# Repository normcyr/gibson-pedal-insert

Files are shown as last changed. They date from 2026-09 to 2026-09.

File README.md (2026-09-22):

# Gibson Bicycle Pedal Insert

3D-printable replacement insert for vintage Gibson bicycle pedals.

These black plastic inserts were originally used in Gibson bicycle
pedals. This project provides a modern replacement that can be
3D-printed for restoration purposes.

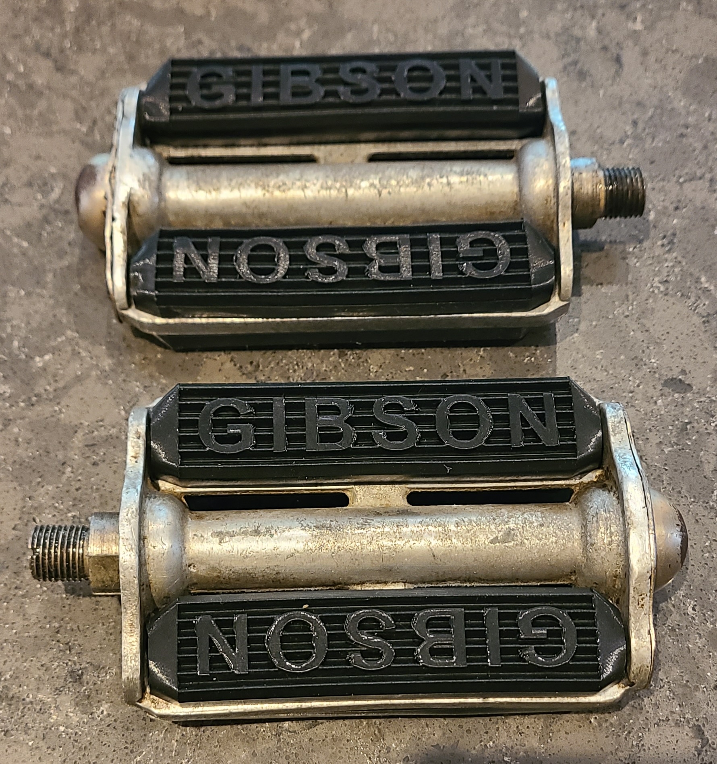
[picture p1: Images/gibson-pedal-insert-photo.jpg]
Gibson pedal with printed insert


## Status

**Version:** 1.0  
**Tested:** Yes - fit tested on an original Gibson bicycle pedal

This is an independent reproduction and is not affiliated with or
endorsed by Gibson.

## Files

- `CAD/`: source CAD files
- `3D-print/`: 3MF and STL files for printing
- `docs/PRINTING.md`: printing recommendations
- `docs/DIMENSIONS.md`: dimensions and measurements

Also viewable and downloadable from the [F360 website here](https://a360.co/4dgqYPB).

## Printing

Recommended starting settings:

- Material: TPU 95A or softer
- Layer height: 0.20 mm
- Walls: 4
- Infill: 20%
- Supports: No
- Brim: 10 mm outer brim
- Orientation: Print vertically

The part should be printed at 100% scale. It will use about 25 g of TPU plastic.

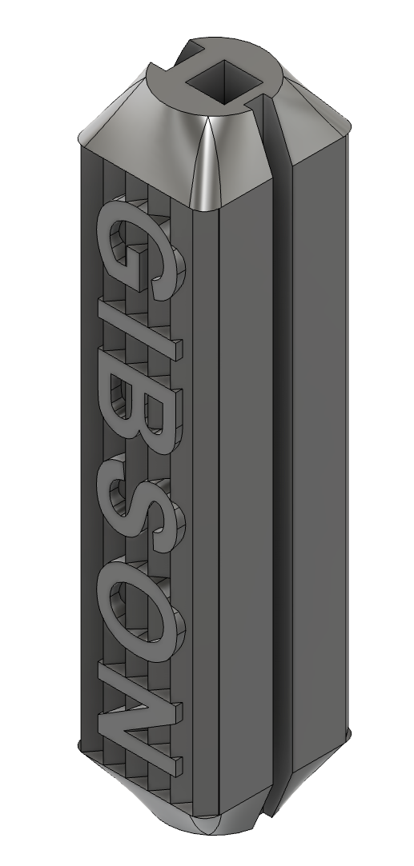
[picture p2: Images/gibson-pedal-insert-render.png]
Gibson pedal insert rendering


See [PRINTING.md](docs/PRINTING.md) for additional information.

## Installation

Align the insert with the pedal opening and press it into place until
it is fully seated.

Check the fit carefully before using the bicycle.

## Background

Gibson pedals appear to be Canadian pedals introduced in the early 1920s,
with a Canadian patent dated July 10, 1923. They were associated with CCM
(Canada Cycle & Motor Co.), which may have distributed or sold them for use
on some of its bicycles, although the available sources do not confirm that
CCM manufactured every Gibson pedal. Examples have been documented on CCM
bicycles from the 1930s and 1940s, including a 1941 ladies' loop-frame model;
this project provides a replacement for its original rubber insert.

### Discussion and reference material

- [The CABE Gibson Pedals thread](https://thecabe.com/forum/threads/gibson-pedals-thread-post-up-your-gibson-photos.224916/)
- [Vintage CCM thread](https://www.vintageccm.com/content/gibson-pedals)

## License

This model is licensed under the
[Creative Commons Attribution 4.0 International License (CC BY 4.0)](https://creativecommons.org/licenses/by/4.0/).

Copyright (c) 2026 Normand Cyr.

You are free to share, modify, and commercially use this model,
provided appropriate credit is given to the original creator.

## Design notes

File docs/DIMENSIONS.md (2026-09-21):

# Dimensions

Use the CAD files in `../CAD/` as the source of truth for exact
dimensions, and print the part at 100% scale.

Drawing files can be found in `../Drawings/`.

The model was created from measurements of an original Gibson pedal
insert.

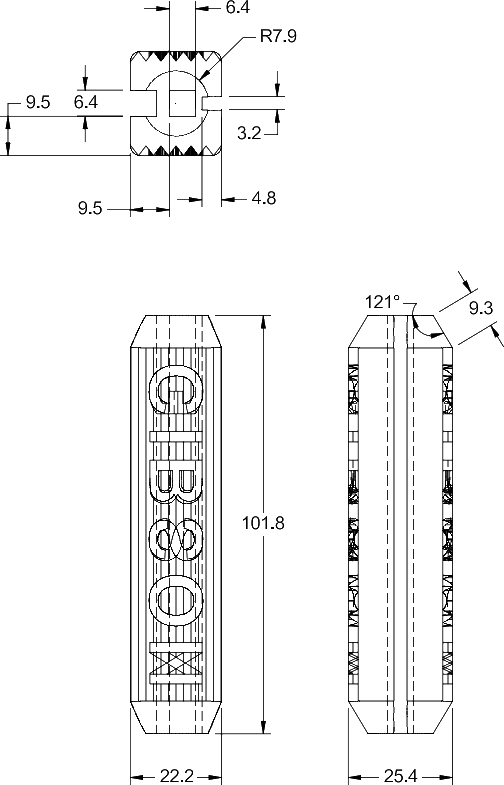
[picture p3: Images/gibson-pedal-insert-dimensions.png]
Gibson pedal insert dimensions


## Main dimensions

All dimensions are in millimetres. The nominal dimensions shown on the
drawing are:

| Dimension | Nominal value |
| --- | ---: |
| Overall length | 101.6 mm |
| Transverse dimension | 22.2 mm |
| Lateral dimension | 25.4 mm |
| Central opening | 6.4 mm |
| End radius | R7.8 mm |
| Top angle | 121° |

The exported STL and 3MF measure approximately 22.225 x 101.775 x 25.400
mm. Print at 100% scale.

The drawing also contains the smaller feature dimensions and should be used
for those details. Verify the fit against the pedal before use.

## Reference discussion

The CABE: Gibson Pedals thread:
<https://thecabe.com/forum/threads/gibson-pedals-thread-post-up-your-gibson-photos.224916/>

The original part was measured directly; dimensions were not obtained
from a manufacturer's CAD file.

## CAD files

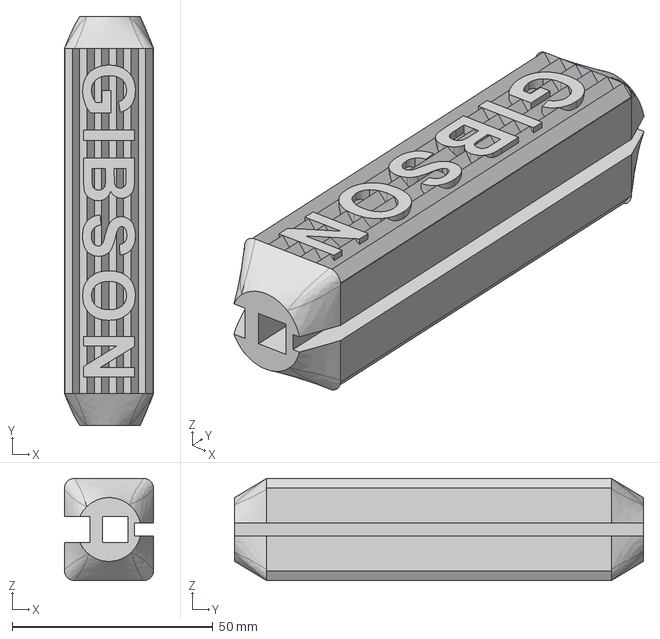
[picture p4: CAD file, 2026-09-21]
CAD/gibson-pedal-insert.step
22.2 x 101.8 x 25.4 mm

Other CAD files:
Drawings/gibson-pedal-insert.dwg
3D-print/gibson-pedal-insert.3mf
3D-print/gibson-pedal-insert.stl
CAD/gibson-pedal-insert.f3d

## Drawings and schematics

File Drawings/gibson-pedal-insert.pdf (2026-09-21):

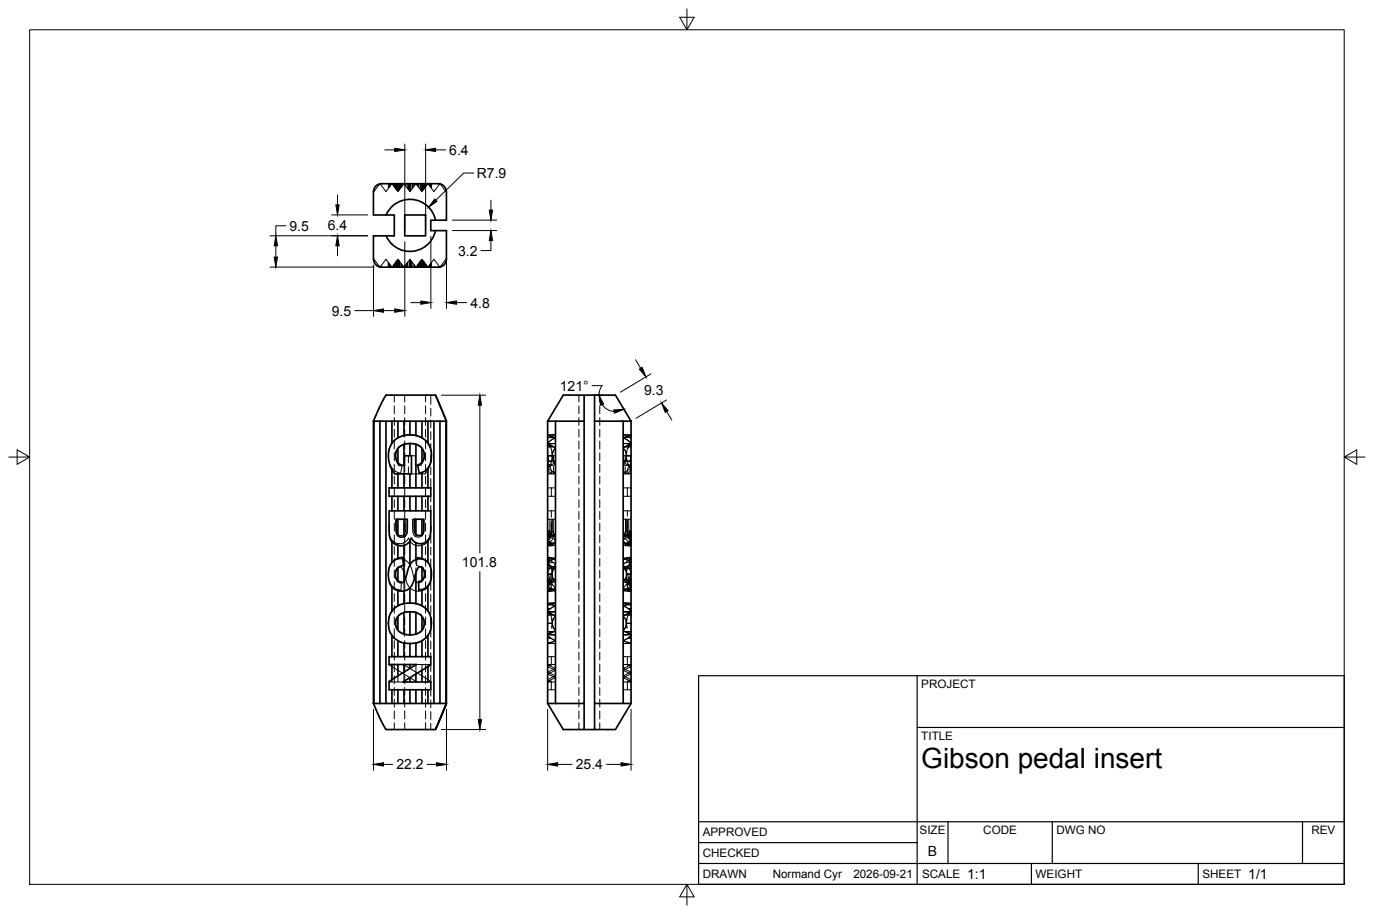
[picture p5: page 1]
SIZE; CODE; DWG NO; REV; Normand Cyr 2026-09-21

TITLE
Gibson pedal insert

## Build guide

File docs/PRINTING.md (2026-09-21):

# Printing

Recommended starting settings:

- Material: TPU
- Layer height: 0.20 mm
- Walls: 4
- Infill: 20%
- Supports: No
- Brim: 10 mm outer brim
- Orientation: Print vertically

Print the insert at 100% scale and confirm fit before use.

Gibson pedal insert rendering

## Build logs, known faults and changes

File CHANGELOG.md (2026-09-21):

# Changelog

## v1.0 — 2026-09-21

- Initial release.
- Model created from measurements of an original Gibson pedal insert.
- Fit tested on pedal.

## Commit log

2026-09-21 Update DIMENSIONS.md with additional context
    Added context about the original Gibson pedal insert and reference discussions.
2026-09-21 Clean up placeholder with real files
    [gibson-pedal-insert.f3d, gibson-pedal-insert.step]
2026-09-21 add real files
    [gibson-pedal-insert.3mf, gibson-pedal-insert.dwg, gibson-pedal-insert.stl]
2026-09-21 docs: document dimensions and clarify printing instructions
